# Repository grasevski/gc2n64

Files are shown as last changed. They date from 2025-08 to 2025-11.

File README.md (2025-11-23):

# gc2n64
Gamecube controller to N64 adapter. Dependencies:

 * [avra](https://github.com/Ro5bert/avra): `apt install avra` - AVR assembler
 * [avrdude](https://github.com/avrdudes/avrdude): `apt install avrdude` - to flash program to ATTiny
 * [KiCAD](https://www.kicad.org/): `apt install kicad` - for schematic
 * [ATTiny9](https://www.microchip.com/en-us/product/attiny9): SOT-23-6 is used for running the code. Attiny 25/45/85 can be used instead if preferred.

Usage:

```
# Build
make

# Flash to attiny9
make flash

# Delete build output
make clean
```

The KiCAD schematic is in the schematic directory. It has a TC2030-NL footprint for flashing and debugging. It is designed to be wired to two respective extension cables for gamecube and n64. Then it can be heatshrunk for neatness and stress relief.

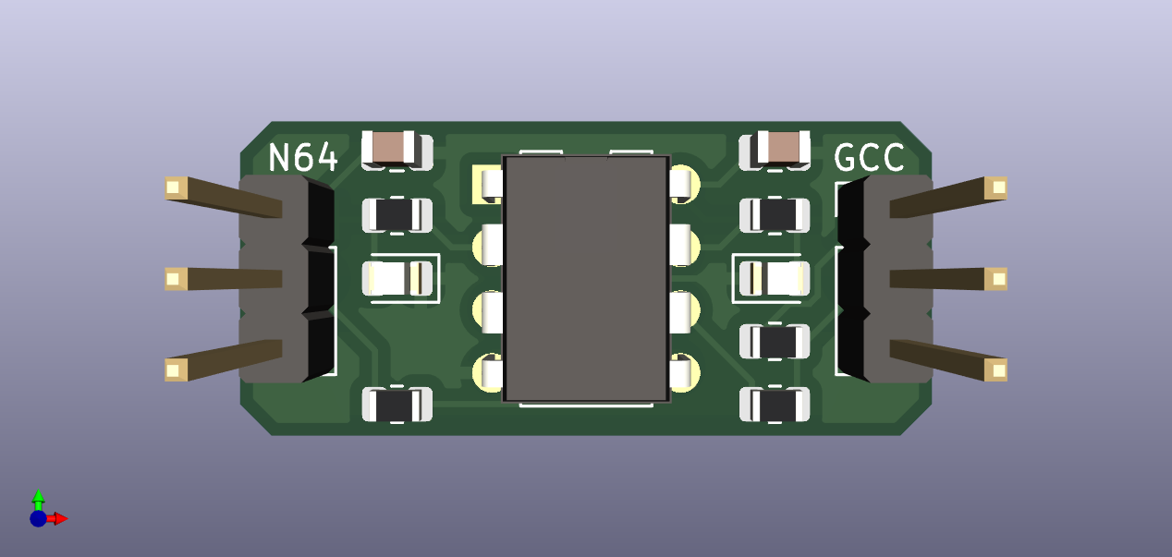
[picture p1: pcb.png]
pcb


schematic

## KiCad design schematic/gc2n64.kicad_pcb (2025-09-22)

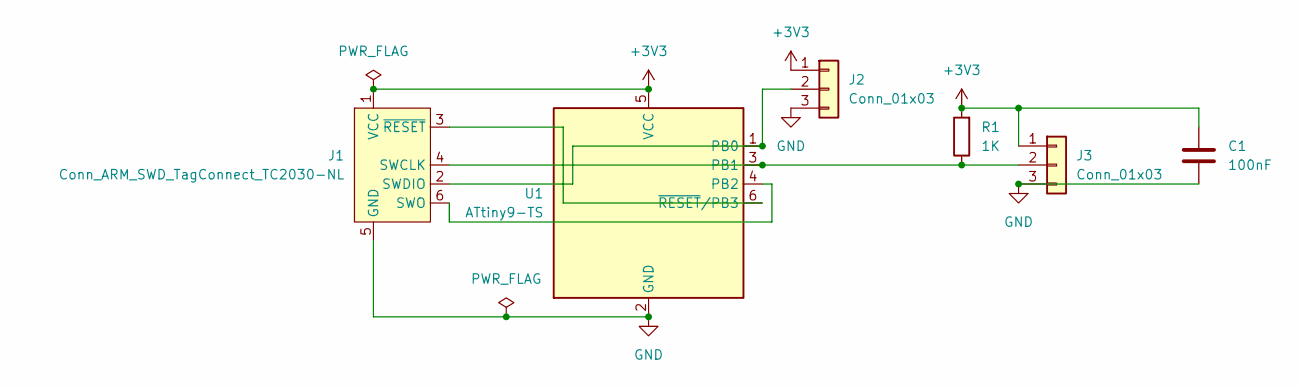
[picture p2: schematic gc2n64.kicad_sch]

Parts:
C1: 100nF; C_0402_1005Metric
J1: Conn_ARM_SWD_TagConnect_TC2030-NL; Tag-Connect_TC2030-IDC-NL_2x03_P1.27mm_Vertical
J2, J3: Conn_01x03; SolderWire-0.1sqmm_1x03_P3.6mm_D0.4mm_OD1mm_Relief2x
R1: 1K; R_0402_1005Metric
U1: ATtiny9-TS; SOT-23-6

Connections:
+3V3: C1.1, J1.1 (VCC), J2.1, J3.1, R1.2, U1.5 (VCC)
GND: C1.2, J1.5 (GND), J2.3, J3.3, U1.2 (GND)
unnamed: J1.4 (SWCLK), J3.2, R1.1, U1.3 (PB1)
unnamed: J1.2 (SWDIO), J2.2, U1.1 (PB0)
unnamed: J1.6 (SWO), U1.4 (PB2)
unnamed: J1.3 (~RESET), U1.6 (~RESET/PB3)

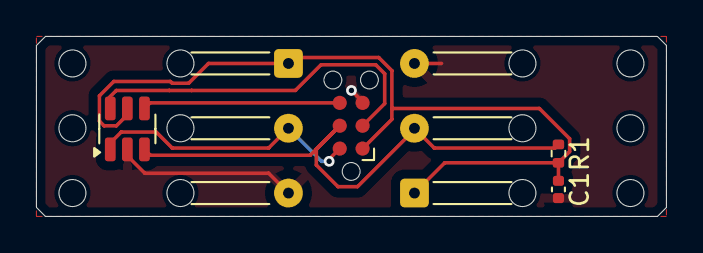
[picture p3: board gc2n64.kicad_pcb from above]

Board: 2 copper layers, 35.0 x 10.0 mm, 6 parts (0 on the bottom side), 6 nets.

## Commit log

2025-08-13 feat(code): first draft
    [gc2n64.kicad_pcb, gc2n64.kicad_sch]
2025-08-26 fix(timing): adjust OSCCAL based on n64 timing
    Timing needs some fine tuning. Power down sleep has too much latency.
    Also, watchdog timer tolerance is too loose. Change to idle sleep, use
    timer0, and calibrate internal oscillator based on n64 request bit
    timing.
2025-09-22 feat(design): revision 2
    Refactored the design to work with either attiny9 or attiny25, using a
    basic hardware abstraction layer. So that the PCB can have a tagconnect
    footprint rather than excessive through holes and plugging and
    unplugging of attiny85 into a socket.
    [gc2n64.kicad_pcb, gc2n64.kicad_sch]
2025-11-15 controller working, but pressing random buttons
2025-11-18 Analog and c buttons working.
2025-11-23 calibrate on startup
